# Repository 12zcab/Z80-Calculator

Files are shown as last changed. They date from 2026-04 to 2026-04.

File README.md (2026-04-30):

BASED ON PREVIOUS PROJECT [View github Repo](https://github.com/12zcab/Handheld-Z80-Retro-Computer)
# What is this?
This is a portable handheld computer made with z80 customized for assembly language programming and simplified system for educational purpose.
The computer contains a Z80 cpu,a 1602 or 2004 LCD and 2 EEPROM slot,a RAM slot,a buzzer with IO ic driver
Its originally designed for another project and edited for better performance as a programmable calculator.
The circuit is edited to make it more simple.

# What it does?
It's a calculator that you can do programming on!
My final goal is to do complex trigonometry and statistic calculation on this calculator!
Also hopefully I can do a Bad Apple Animation on this device XD

Main Functions:
|Type|Function|
|-|-|
|Varaible|ABCDEHIJKLMNOPQRSTUVWXYZ 26 in total :D Hopefully can support 1*10^-99 to 9.999999999*10^99|
|basic operation|+ - * /|
|Trigo|Sin Cos Tan,ArcSin ArcCos ArcTan|
|Sqrt and indexes|^ NthRoot Sqr Sqrt|
|Log|Ln,Log,e^,10^|
|Formula|Save custom formula to input variables and output the result|
# Why it exists?
I just learnt how computer calculates complicated functions with taylor series simplification and I wanna try it in real life and make my own cool retro calculator :D

# Basic Structure

\##Memory Map

|Address|Compoenent|Function|
|-|-|-|
|0x0000 - 0x7FFF|EEPROM|Executable Code of Operating System|
|0x8000 - 0xFEFF|RAM or EEPROM|Multibanked External EEPROM and RAM|
|0xFF00 - 0xFFFF|IO Outputs|for LCD Buzzer and Keyboard Input Output|
|----|----|----|

# Compoenents
## Main Compoenents

|Name|Usage|Quantity|
|-|-|-|

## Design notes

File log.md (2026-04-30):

Day1 24/4/2026

What Ive done today:

Edited the README.md file

Edited the Circuit for 1602 and buzzer driver

Edited the Programmer manual.

Day2 30/4/2026

What Ive done today:

Edited the README.md file
Rearranged the multibank circuit for easier soldering(DIP:D)
Assigned a better footprint for the PCB

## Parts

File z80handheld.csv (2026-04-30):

Qty | Value | Footprint | Datasheet
1 | Battery_Cell | Battery:BatteryHolder_MYOUNG_BS-07-A1BJ001_CR2032
1 | Buzzer | Buzzer_Beeper:Buzzer_12x9.5RM7.6
39 | LED | LED_THT:LED_D5.0mm
1 | WC1602A | Display:WC1602A | http://www.wincomlcd.com/pdf/WC1602A-SFYLYHTC06.pdf
1 | DS12885+ | Library:DIP1524W51P254L3175H508Q24N | http://datasheets.maximintegrated.com/en/ds/DS12885-DS12C887A.pdf
1 | Power | Connector_PinHeader_2.54mm:PinHeader_1x02_P2.54mm_Vertical
4 | 10k | Resistor_THT:R_Axial_DIN0207_L6.3mm_D2.5mm_P7.62mm_Horizontal
1 | 1k | Resistor_THT:R_Axial_DIN0207_L6.3mm_D2.5mm_P7.62mm_Horizontal
1 | R_Potentiometer | Potentiometer_THT:Potentiometer_ACP_CA9-V10_Vertical
64 | SW_Push_45deg | Button_Switch_SMD:SW_SPST_PTS810
1 | SW_Push | Button_Switch_THT:SW_PUSH_6mm
2 | 74HC04 | Package_DIP:DIP-14_W7.62mm | https://assets.nexperia.com/documents/data-sheet/74HC_HCT04.pdf
1 | 4068 | Package_DIP:DIP-14_W7.62mm | http://www.ti.com/lit/ds/symlink/cd4068b.pdf
1 | 74154 | Package_DIP:DIP-24_W7.62mm | https://www.ti.com/lit/gpn/CD74HCT154
1 | 74LS573 IO0 | Package_DIP:DIP-20_W7.62mm | https://assets.nexperia.com/documents/data-sheet/74HC_HCT573.pdf
1 | 74LS573 | Package_DIP:DIP-20_W7.62mm | https://assets.nexperia.com/documents/data-sheet/74HC_HCT573.pdf
1 | CY62256-70PC | Package_DIP:DIP-28_W15.24mm | https://ecee.colorado.edu/~mcclurel/Cypress_SRAM_CY62256.pdf
1 | 28C256 Additional | Package_DIP:DIP-28_W15.24mm | http://ww1.microchip.com/downloads/en/DeviceDoc/doc0006.pdf
1 | 28C256 | Package_DIP:DIP-28_W15.24mm | http://ww1.microchip.com/downloads/en/DeviceDoc/doc0006.pdf
1 | Z84C00xxP | Package_DIP:DIP-40_W15.24mm | https://archive.org/details/zilog-z-8400
1 | 74LS573 IO1 | Package_DIP:DIP-20_W7.62mm | https://assets.nexperia.com/documents/data-sheet/74HC_HCT573.pdf
1 | SN76489AN | Package_DIP:DIP-16_W7.62mm | https://www.vgmpf.com/Wiki/images/7/78/SN76489AN_-_Manual.pdf
1 | 74HCT02 | Package_DIP:DIP-14_W7.62mm | http://www.ti.com/lit/gpn/sn74hct02
1 | 20MHZ | Oscillator:Oscillator_DIP-14 | http://cdn-reichelt.de/documents/datenblatt/B400/OSZI.pdf
1 | Crystal 32768Hz | Crystal:Crystal_C38-LF_D3.0mm_L8.0mm_Vertical
1 | 4MHZ | Oscillator:Oscillator_DIP-14 | http://cdn-reichelt.de/documents/datenblatt/B400/OSZI.pdf

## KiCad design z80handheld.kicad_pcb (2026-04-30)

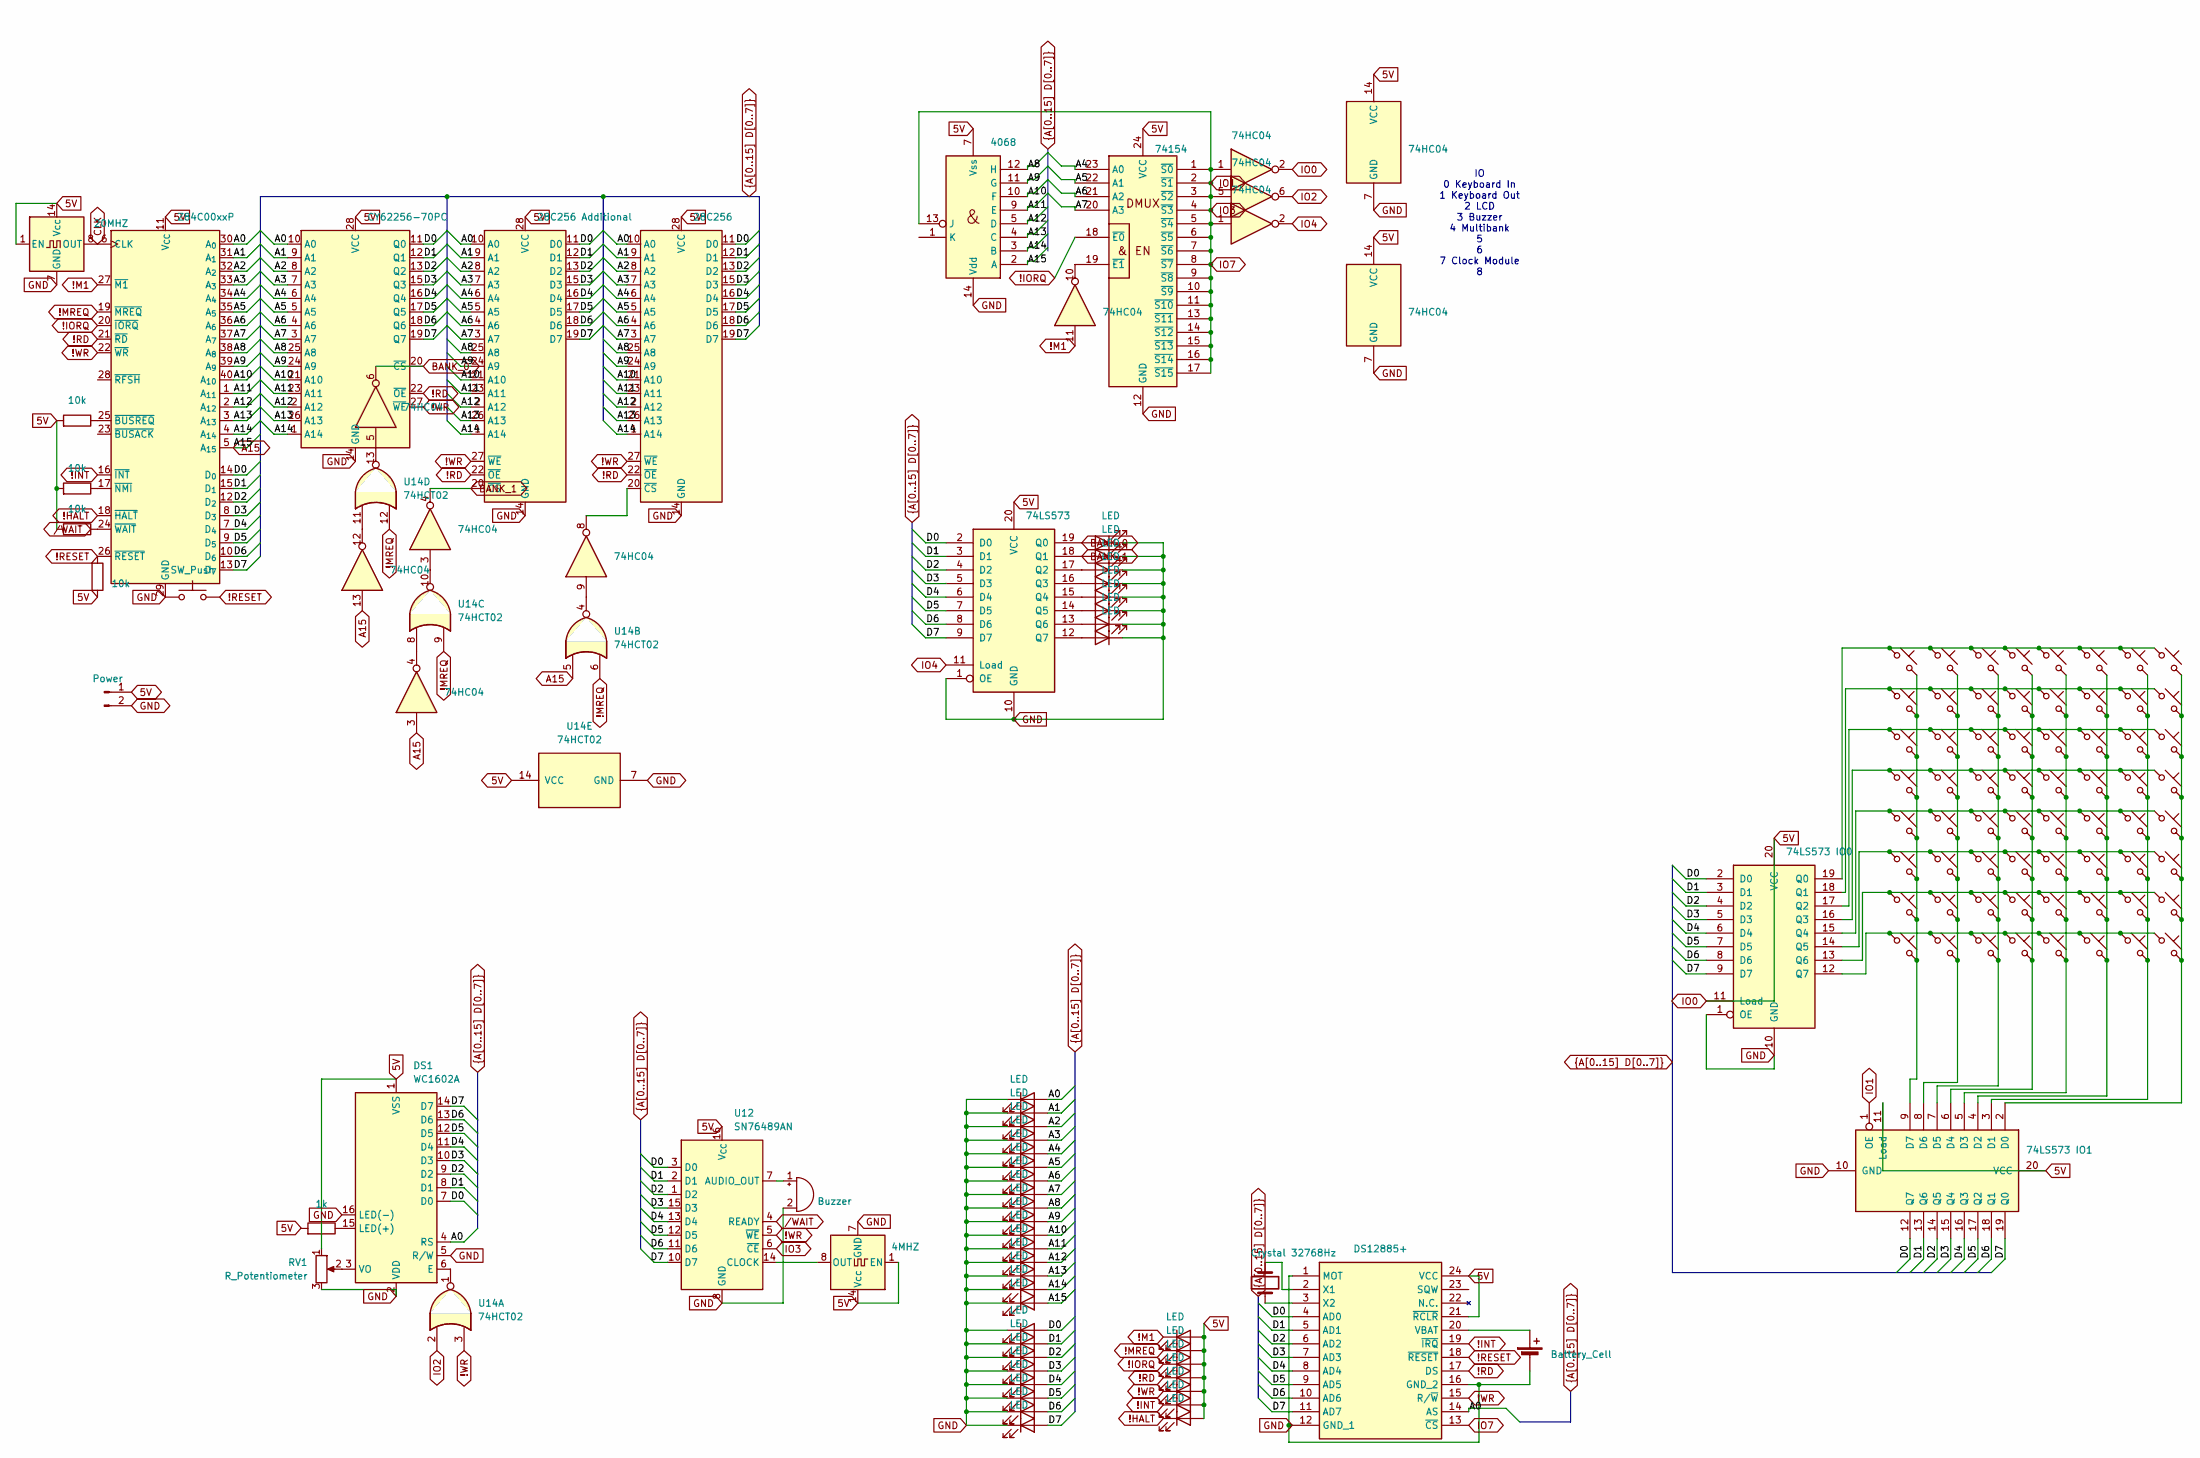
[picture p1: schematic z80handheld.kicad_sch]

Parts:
BT1: Battery_Cell; BatteryHolder_MYOUNG_BS-07-A1BJ001_CR2032
BZ1: Buzzer; Buzzer_12x9.5RM7.6
D1, D2, D3, D4, D5, D6, D7, D8, D9, D10, D11, D12, D13, D14, D15, D16, D17, D18, D19, D20, D21, D22, D23, D24, D25, D26, D27, D28, D29, D30, D31, D32, D33, D34, D35, D36, D37, D38, D39: LED; LED_D5.0mm
DS1: WC1602A
IC1: DS12885+; DIP1524W51P254L3175H508Q24N; Manufacturer_Part_Number DS12885+; Mouser Part Number 700-DS12885
J1: Power; PinHeader_1x02_P2.54mm_Vertical
R1, R2, R3, R5: 10k; R_Axial_DIN0207_L6.3mm_D2.5mm_P7.62mm_Horizontal
R4: 1k; R_Axial_DIN0207_L6.3mm_D2.5mm_P7.62mm_Horizontal
RV1: R_Potentiometer; Potentiometer_ACP_CA9-V10_Vertical
SW1, SW2, SW3, SW4, SW5, SW6, SW7, SW8, SW9, SW10, SW11, SW12, SW13, SW14, SW15, SW16, SW17, SW18, SW19, SW20, SW21, SW22, SW23, SW24, SW25, SW26, SW27, SW28, SW29, SW30, SW31, SW32, SW33, SW34, SW35, SW36, SW37, SW38, SW39, SW40, SW41, SW42, SW43, SW44, SW45, SW46, SW47, SW48, SW49, SW50, SW51, SW52, SW53, SW54, SW55, SW56, SW57, SW58, SW59, SW60, SW61, SW62, SW63, SW64: SW_Push_45deg; SW_SPST_PTS810
SW65: SW_Push; SW_PUSH_6mm
U1, U3: 74HC04; DIP-14_W7.62mm
U2: 4068; DIP-14_W7.62mm
U4: 74154; DIP-24_W7.62mm
U5: 74LS573 IO0; DIP-20_W7.62mm
U6: 74LS573; DIP-20_W7.62mm
U7: CY62256-70PC; DIP-28_W15.24mm
U8: 28C256 Additional; DIP-28_W15.24mm
U9: 28C256; DIP-28_W15.24mm
U10: Z84C00xxP; DIP-40_W15.24mm
U11: 74LS573 IO1; DIP-20_W7.62mm
U12: SN76489AN; DIP-16_W7.62mm
U14: 74HCT02; DIP-14_W7.62mm
Y1: 20MHZ; Oscillator_DIP-14
Y2: Crystal 32768Hz; Crystal_C38-LF_D3.0mm_L8.0mm_Vertical
Y3: 4MHZ; Oscillator_DIP-14

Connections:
5V: D6.2 (A), D9.2 (A), D12.2 (A), D15.2 (A), D18.2 (A), D21.2 (A), D24.2 (A), DS1.1 (VSS), IC1.21 (~RCLR), IC1.24 (VCC), J1.1, R1.1, R2.1, R3.1, R5.2, RV1.1, U1.2, U1.14 (VCC), U2.7 (Vss), U3.14 (VCC), U4.24 (VCC), U5.11 (Load), U5.20 (VCC), U6.20 (VCC), U7.28 (VCC), U8.28 (VCC), U9.28 (VCC), U10.11 (V_{CC}), U11.11 (Load), U11.20 (VCC), U12.16 (V_{CC}), U14.14 (VCC), Y1.1 (EN), Y1.14 (Vcc), Y3.1 (EN), Y3.14 (Vcc)
!HALT: D6.1 (K), U10.18 (~HALT)
!INT: D9.1 (K), IC1.19 (~IRQ), U10.16 (~INT)
!IORQ: D18.1 (K), U4.18 (~E0), U10.20 (~IORQ)
!M1: D24.1 (K), U1.11, U10.27 (~M1)
!MREQ: D21.1 (K), U10.19 (~MREQ), U14.6, U14.9, U14.12
!RD: D15.1 (K), IC1.17 (DS), U7.22 (~OE), U8.22 (~OE), U9.22 (~OE), U10.21 (~RD)
!RESET: IC1.18 (~RESET), R5.1, SW65.2, U10.26 (~RESET)
!WR: D12.1 (K), IC1.15 (R/~W), U7.27 (~WE), U8.27 (~WE), U9.27 (~WE), U10.22 (~WR), U12.5 (~WE), U14.3
A0: D1.2 (A), DS1.4 (RS), IC1.14 (AS), U7.10 (A0), U8.10 (A0), U9.10 (A0), U10.30 (A_{0})
A1: D2.2 (A), U7.9 (A1), U8.9 (A1), U9.9 (A1), U10.31 (A_{1})
A2: D4.2 (A), U7.8 (A2), U8.8 (A2), U9.8 (A2), U10.32 (A_{2})
A3: D7.2 (A), U7.7 (A3), U8.7 (A3), U9.7 (A3), U10.33 (A_{3})
A4: D10.2 (A), U4.23 (A0), U7.6 (A4), U8.6 (A4), U9.6 (A4), U10.34 (A_{4})
A5: D13.2 (A), U4.22 (A1), U7.5 (A5), U8.5 (A5), U9.5 (A5), U10.35 (A_{5})
A6: D16.2 (A), U4.21 (A2), U7.4 (A6), U8.4 (A6), U9.4 (A6), U10.36 (A_{6})
A7: D19.2 (A), U4.20 (A3), U7.3 (A7), U8.3 (A7), U9.3 (A7), U10.37 (A_{7})
A8: D22.2 (A), U2.12 (H), U7.25 (A8), U8.25 (A8), U9.25 (A8), U10.38 (A_{8})
A9: D25.2 (A), U2.11 (G), U7.24 (A9), U8.24 (A9), U9.24 (A9), U10.39 (A_{9})
A10: D26.2 (A), U2.10 (F), U7.21 (A10), U8.21 (A10), U9.21 (A10), U10.40 (A_{10})
A11: D27.2 (A), U2.9 (E), U7.23 (A11), U8.23 (A11), U9.23 (A11), U10.1 (A_{11})
A12: D28.2 (A), U2.5 (D), U7.2 (A12), U8.2 (A12), U9.2 (A12), U10.2 (A_{12})
A13: D29.2 (A), U2.4 (C), U7.26 (A13), U8.26 (A13), U9.26 (A13), U10.3 (A_{13})
A14: D30.2 (A), U2.3 (B), U7.1 (A14), U8.1 (A14), U9.1 (A14), U10.4 (A_{14})
A15: D31.2 (A), U1.3, U1.13, U2.2 (A), U10.5 (A_{15}), U14.5
BANK_0: D3.2 (A), U3.6, U6.19 (Q0), U7.20 (~CS)
BANK_1: D5.2 (A), U3.4, U6.18 (Q1), U8.20 (~CS)
CLK: U10.6 (CLK), Y1.8 (OUT)
D0: D32.2 (A), DS1.7 (D0), IC1.4 (AD0), U5.2 (D0), U6.2 (D0), U7.11 (Q0), U8.11 (D0), U9.11 (D0), U10.14 (D_{0}), U11.12 (Q7), U12.3 (D0)
D1: D33.2 (A), DS1.8 (D1), IC1.5 (AD1), U5.3 (D1), U6.3 (D1), U7.12 (Q1), U8.12 (D1), U9.12 (D1), U10.15 (D_{1}), U11.13 (Q6), U12.2 (D1)
D2: D34.2 (A), DS1.9 (D2), IC1.6 (AD2), U5.4 (D2), U6.4 (D2), U7.13 (Q2), U8.13 (D2), U9.13 (D2), U10.12 (D_{2}), U11.14 (Q5), U12.1 (D2)
D3: D35.2 (A), DS1.10 (D3), IC1.7 (AD3), U5.5 (D3), U6.5 (D3), U7.15 (Q3), U8.15 (D3), U9.15 (D3), U10.8 (D_{3}), U11.15 (Q4), U12.15 (D3)
D4: D36.2 (A), DS1.11 (D4), IC1.8 (AD4), U5.6 (D4), U6.6 (D4), U7.16 (Q4), U8.16 (D4), U9.16 (D4), U10.7 (D_{4}), U11.16 (Q3), U12.13 (D4)
D5: D37.2 (A), DS1.12 (D5), IC1.9 (AD5), U5.7 (D5), U6.7 (D5), U7.17 (Q5), U8.17 (D5), U9.17 (D5), U10.9 (D_{5}), U11.17 (Q2), U12.12 (D5)
D6: D38.2 (A), DS1.13 (D6), IC1.10 (AD6), U5.8 (D6), U6.8 (D6), U7.18 (Q6), U8.18 (D6), U9.18 (D6), U10.10 (D_{6}), U11.18 (Q1), U12.11 (D6)
D7: D39.2 (A), DS1.14 (D7), IC1.11 (AD7), U5.9 (D7), U6.9 (D7), U7.19 (Q7), U8.19 (D7), U9.19 (D7), U10.13 (D_{7}), U11.19 (Q0), U12.10 (D7)
GND: BT1.2 (-), BZ1.2 (-), D1.1 (K), D2.1 (K), D3.1 (K), D4.1 (K), D5.1 (K), D7.1 (K), D8.1 (K), D10.1 (K), D11.1 (K), D13.1 (K), D14.1 (K), D16.1 (K), D17.1 (K), D19.1 (K), D20.1 (K), D22.1 (K), D23.1 (K), D25.1 (K), D26.1 (K), D27.1 (K), D28.1 (K), D29.1 (K), D30.1 (K), D31.1 (K), D32.1 (K), D33.1 (K), D34.1 (K), D35.1 (K), D36.1 (K), D37.1 (K), D38.1 (K), D39.1 (K), DS1.2 (VDD), DS1.5 (R/W), DS1.16 (LED(-)), IC1.1 (MOT), IC1.12 (GND_1), IC1.16 (GND_2), J1.2, RV1.3, SW65.1, U1.7 (GND), U2.14 (Vdd), U3.7 (GND), U4.12 (GND), U5.1 (OE), U5.10 (GND), U6.1 (OE), U6.10 (GND), U7.14 (GND), U8.14 (GND), U9.14 (GND), U10.29 (GND), U11.10 (GND), U12.8 (GND), U14.7 (GND), Y1.7 (GND), Y3.7 (GND)
IO1: IC1.13 (~CS), U1.1, U1.5, U2.13 (J), U3.1, U4.1 (~S0), U4.2 (~S1), U4.3 (~S2), U4.4 (~S3), U4.5 (~S4), U4.6 (~S5), U4.7 (~S6), U4.8 (~S7), U4.9 (~S8), U4.10 (~S9), U4.11 (~S10), U4.13 (~S11), U4.14 (~S12), U4.15 (~S13), U4.16 (~S14), U4.17 (~S15), U11.1 (OE), U12.6 (~CE)
IO2: U1.6, U14.2
IO4: U3.2, U6.11 (Load)
unnamed: BT1.1 (+), IC1.20 (VBAT)
unnamed: BZ1.1 (+), U12.7 (AUDIO_OUT)
unnamed: D8.2 (A), U6.17 (Q2)
unnamed: D11.2 (A), U6.16 (Q3)
unnamed: D14.2 (A), U6.15 (Q4)
unnamed: D17.2 (A), U6.14 (Q5)
unnamed: D20.2 (A), U6.13 (Q6)
unnamed: D23.2 (A), U6.12 (Q7)
unnamed: DS1.6 (E), U14.1
unnamed: DS1.15 (LED(+)), R4.2
unnamed: DS1.3 (VO), RV1.2
unnamed: IC1.2 (X1), Y2.2
unnamed: IC1.3 (X2), Y2.1
unnamed: U1.4, U14.8
unnamed: U1.9, U14.4
unnamed: U1.12, U14.11
unnamed: U1.10, U4.19 (~E1)
unnamed: SW1.1, SW2.1, SW3.1, SW4.1, SW5.1, SW6.1, SW7.1, SW8.1, U5.19 (Q0)
unnamed: SW9.1, SW10.1, SW11.1, SW12.1, SW13.1, SW14.1, SW15.1, SW16.1, U5.18 (Q1)
unnamed: SW17.1, SW18.1, SW19.1, SW20.1, SW21.1, SW22.1, SW23.1, SW24.1, U5.17 (Q2)
unnamed: SW25.1, SW26.1, SW27.1, SW28.1, SW29.1, SW30.1, SW31.1, SW32.1, U5.16 (Q3)
unnamed: SW33.1, SW34.1, SW35.1, SW36.1, SW37.1, SW38.1, SW39.1, SW40.1, U5.15 (Q4)
unnamed: SW41.1, SW42.1, SW43.1, SW44.1, SW45.1, SW46.1, SW47.1, SW48.1, U5.14 (Q5)
unnamed: SW49.1, SW50.1, SW51.1, SW52.1, SW53.1, SW54.1, SW55.1, SW56.1, U5.13 (Q6)
unnamed: SW57.1, SW58.1, SW59.1, SW60.1, SW61.1, SW62.1, SW63.1, SW64.1, U5.12 (Q7)
unnamed: U1.8, U9.20 (~CS)
unnamed: R1.2, U10.25 (~BUSREQ)
unnamed: R2.2, U10.17 (~NMI)
unnamed: R3.2, U10.24 (~WAIT)
unnamed: SW8.2, SW16.2, SW24.2, SW32.2, SW40.2, SW48.2, SW56.2, SW64.2, U11.2 (D0)
unnamed: SW7.2, SW15.2, SW23.2, SW31.2, SW39.2, SW47.2, SW55.2, SW63.2, U11.3 (D1)
unnamed: SW6.2, SW14.2, SW22.2, SW30.2, SW38.2, SW46.2, SW54.2, SW62.2, U11.4 (D2)
unnamed: SW5.2, SW13.2, SW21.2, SW29.2, SW37.2, SW45.2, SW53.2, SW61.2, U11.5 (D3)
unnamed: SW4.2, SW12.2, SW20.2, SW28.2, SW36.2, SW44.2, SW52.2, SW60.2, U11.6 (D4)
unnamed: SW3.2, SW11.2, SW19.2, SW27.2, SW35.2, SW43.2, SW51.2, SW59.2, U11.7 (D5)
unnamed: SW2.2, SW10.2, SW18.2, SW26.2, SW34.2, SW42.2, SW50.2, SW58.2, U11.8 (D6)
unnamed: SW1.2, SW9.2, SW17.2, SW25.2, SW33.2, SW41.2, SW49.2, SW57.2, U11.9 (D7)
unnamed: U12.14 (CLOCK), Y3.8 (OUT)
unnamed: U3.3, U14.10
unnamed: U3.5, U14.13
/WAIT: U12.4 (READY)

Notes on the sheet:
IO 0 Keyboard In 1 Keyboard Out 2 LCD 3 Buzzer 4 Multibank 5 6 7 Clock Module 8

Board: 2 copper layers, 131 parts (0 on the bottom side), 80 nets, no tracks yet.

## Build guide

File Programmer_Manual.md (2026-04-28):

# Features
1.LCD1602 or LCD2004
2.Multibank RAM/EEPROM and Status LED Output
3.DS12885+ Clock Module
4.Keyboard
5.Buzzer IC output

# LCD1602 or LCD2004
not yet finished

# Multibank RAM/EEPROM and Status LED Programming

It's just basically a 74hc573 on IO Port 4(0xFF40).
Bit 0: Low\_Activate ChipSelect Signal for 32k RAM on address 0x8000 to 0xFEFF
Bit 1: Low\_Activate ChipSelect Signal for EEPROM on address 0x8000 to 0xFEFF
Bit 2-7: Status LED on board

```z80asm
; Define IO Address
BANK\_REG   EQU 0xFF40

; Enable EEPROM and Disable RAM and Turn Off all LEDs
ld a, 01h
out (BANK\_REG), a

; Enable RAM and Disable EEPROM and Turn On all LEDs
ld a, FEh
out (BANK\_REG), a
```

# DS12885+ Clock Module Programming [Reference Document](https://www.analog.com/media/en/technical-documentation/data-sheets/DS12885-DS12C887A.pdf)

It's on the IO  Port of the Z80.
The Clock Module have two modes : BCD Mode and Binary Mode

### Table 2A. Time, Calendar, and Alarm Data Modes—BCD Mode (DM = 0)

|ADDRESS|BIT 7|BIT 6|BIT 5|BIT 4|BIT 3|BIT 2|BIT 1|BIT 0|FUNCTION|RANGE|
|-|:-:|:-:|:-:|:-:|:-:|:-:|:-:|:-:|-|-|
|00H|0|<-|10 Seconds|->|<-|Seconds|->||Seconds|00–59|
|01H|0|<-|10 Seconds|->|<-|Seconds|->||Seconds Alarm|00–59|
|02H|0|<-|10 Minutes|->|<-|Minutes|->||Minutes|00–59|
|03H|0|<-|10 Minutes|->|<-|Minutes|->||Minutes Alarm|00–59|
|04H|AM/PM|0|10 Hours||<-|Hours|->||Hours|1–12 +AM/PM / 00–23|
|05H|AM/PM|0|10 Hours||<-|Hours|->||Hours Alarm|1–12 +AM/PM / 00–23|
|06H|0|0|0|0|0|<-|Day|->|Day|01–07|
|07H|0|0|<-|10 Date|<-|Date|->||Date|01–31|
|08H|0|0|0|10 Mo.|<-|Month|->||Months|01–12|
|09H|<-|10 Years|->||<-|Year|->||Year|00–99|
|0AH|UIP|DV2|DV1|DV0|RS3|RS2|RS1|RS0|Control|—|
|0BH|SET|PIE|AIE|UIE|SQWE|DM|24/12|DSE|Control|—|
|0CH|IRQF|PF|AF|UF|0|0|0|0|Control|—|
|0DH|VRT|0|0|0|0|0|0|0|Control|—|
|0EH-31H|X|X|X|X|X|X|X|X|RAM|—|
|32H|<-|10 Century|->||<-|Century\*|->||Century\*|00–99|
|33H-7FH|X|X|X|X|X|X|X|X|RAM|—|

\---

### Table 2B. Time, Calendar, and Alarm Data Modes—Binary Mode (DM = 1)

|ADDRESS|BIT 7|BIT 6|BIT 5|BIT 4|BIT 3|BIT 2|BIT 1|BIT 0|FUNCTION|RANGE|
|-|:-:|:-:|:-:|:-:|:-:|:-:|:-:|:-:|-|-|
|00H|0|0|<-|->|Seconds|<-|->||Seconds|00–3B|
|01H|0|0|<-|->|Seconds|<-|->||Seconds Alarm|00–3B|
|02H|0|0|<-|->|Minutes|<-|->||Minutes|00–3B|
|03H|0|0|<-|->|Minutes|<-|->||Minutes Alarm|00–3B|
|04H|AM/PM|0|0|<-|->|Hours|<-|->|Hours|01–0C +AM/PM / 00–17|
|05H|AM/PM|0|0|<-|->|Hours|<-|->|Hours Alarm|01–0C +AM/PM / 00–17|
|06H|0|0|0|0|0|<-|Day|->|Day|01–07|
|07H|0|0|0|<-|->|Date|<-|->|Date|01–1F|
|08H|0|0|0|0|<-|->|Month||Months|01–0C|
|09H|0|<-|->|Year|<-|->|<-|->|Year|00–63|
|0AH|UIP|DV2|DV1|DV0|RS3|RS2|RS1|RS0|Control|—|
|0BH|SET|PIE|AIE|UIE|SQWE|DM|24/12|DSE|Control|—|
|0CH|IRQF|PF|AF|UF|0|0|0|0|Control|—|
|0DH|VRT|0|0|0|0|0|0|0|Control|—|
|0EH-31H|X|X|X|X|X|X|X|X|RAM|—|
|32H|N/A|N/A|<-|->|Century\*|<-|->||Century\*|—|
|33H-7FH|X|X|X|X|X|X|X|X|RAM|—|

\---

**Notes:**

* **X** = Read/Write Bit.
* **\*** = DS12C887, DS12C887A only. General-purpose RAM on DS12885, DS12887, and DS12887A.
* **Note**: Unless otherwise specified, the state of the registers is not defined when power is first applied. Except for the seconds register, 0 bits in the time and date registers can be written to 1, but may be modified when the clock updates. 0 bits should always be written to 0 except for alarm mask bits.

```z80asm
; =====================================================================
; DS12885+ REAL TIME CLOCK DRIVER (Z80)
; Port Mapping:
; FF71h -> AS High (Address Strobe High)
; FF70h -> AS Low  (Latch Address / Data Access)
; =====================================================================

; --- Port Definitions ---
RTC\_CMD      EQU 0FF71h    ; Port with A0=1 (AS High)
RTC\_DATA     EQU 0FF70h    ; Port with A0=0 (AS Low)

; --- Internal Register Map ---
RTC\_SEC      EQU 00h       ; Seconds
RTC\_MIN      EQU 02h       ; Minutes
RTC\_HOUR     EQU 04h       ; Hours
RTC\_DAY\_WEEK EQU 06h       ; Day of week (1-7)
RTC\_DAY\_MON  EQU 07h       ; Day of month (1-31)
RTC\_MONTH    EQU 08h       ; Month (1-12)
RTC\_YEAR     EQU 09h       ; Year (00-99)
RTC\_REG\_A    EQU 0Ah       ; Status Register A
RTC\_REG\_B    EQU 0Bh       ; Status Register B

; =====================================================================
; INITIALIZATION: Setup Oscillator and 24-Hour BCD Mode
; =====================================================================
INIT\_RTC:
    ; 1. Setup Register A: Turn on the 32.768kHz oscillator
    LD A, RTC\_REG\_A
    CALL SELECT\_REG
    LD A, 00100000b       ; DV2-0 = 010 (Osc On), RS3-0 = 0000 (None)
    OUT (C), A

    ; 2. Setup Register B: 24Hr mode, BCD format, Daylight Savings Off
    LD A, RTC\_REG\_B
    CALL SELECT\_REG
    LD A, 00000010b       ; DM=0 (BCD), 24/12=1 (24Hr), DSE=0
    OUT (C), A
    RET

; =====================================================================
; READ TIME: Safely reads Seconds, Minutes, and Hours
; Returns: H = Hours, D = Minutes, E = Seconds (all BCD)
; =====================================================================
GET\_TIME:
    ; Step 1: Wait for Update-In-Progress (UIP) bit to be clear
    ; This ensures we don't read data while the clock is updating.
WAIT\_RTC:
    LD A, RTC\_REG\_A
    CALL SELECT\_REG
    IN A, (C)
    AND 80h               ; Check bit 7 (UIP)
    JR NZ, WAIT\_RTC       ; Loop if update is in progress

    ; Step 2: Read values
    LD A, RTC\_SEC
    CALL SELECT\_REG
    IN E, (C)             ; E = Seconds

    LD A, RTC\_MIN
    CALL SELECT\_REG
    IN D, (C)             ; D = Minutes

    LD A, RTC\_HOUR
    CALL SELECT\_REG
    IN H, (C)             ; H = Hours
    RET

; =====================================================================
; WRITE TIME: Set clock to 14:05:00 (Example)
; =====================================================================
SET\_TIME\_EXAMPLE:
    ; 1. Enter "Set Mode" (Stop updates)
    LD A, RTC\_REG\_B
    CALL SELECT\_REG
    LD A, 10000010b       ; Set SET bit (7) to 1
    OUT (C), A

    ; 2. Write New Time (14:05:00)
    LD A, RTC\_SEC
    CALL SELECT\_REG
    LD A, 00h
    OUT (C), A

    LD A, RTC\_MIN
    CALL SELECT\_REG
    LD A, 05h
    OUT (C), A

    LD A, RTC\_HOUR
    CALL SELECT\_REG
    LD A, 14h             ; 2 PM in BCD
    OUT (C), A

    ; 3. Exit "Set Mode" (Resume updates)
    LD A, RTC\_REG\_B
    CALL SELECT\_REG
    LD A, 00000010b       ; Clear SET bit
    OUT (C), A
    RET

; =====================================================================
; HELPER: Multiplexed Address Latch
; Input: A = Register Index
; Output: BC = RTC\_DATA port address for subsequent IN/OUT
; =====================================================================
SELECT\_REG:
    LD BC, RTC\_CMD        ; A0 = 1 (AS High)
    OUT (C), A            ; Put index on data bus
    LD BC, RTC\_DATA       ; A0 = 0 (AS High-to-Low transition)
    OUT (C), A            ; Address is now latched inside DS12885
    RET

```

# Keyboard Programming

Keyboard is connected to two 74hc573s,IO Port 0 (0xFF00) for Row Select and IO Port 1(0xFF10) for Column Read.
Although the keyboard is wired as a 8x8 matrix,the layout on the PCB is 16\*4.
Please refer to the KiCad Design before programming as the layout is a bit hard to describe in pure text document.
Note that as no diodes are connected to the keyboard circuit, multiple(more than two) keypress may cause glitched input

```z80asm
COL   EQU 0xFF00
ROW   EQU 0xFF10
; Select Column
LD A,01h
OUT (COL),A
; Read Row
IN A,(ROW)
```

# Buzzer Output Programming
Not yet Finished
